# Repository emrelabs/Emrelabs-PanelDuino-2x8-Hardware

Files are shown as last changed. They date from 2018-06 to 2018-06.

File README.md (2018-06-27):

# emrelabs PanelDuino-2x8 Hardware

Please support us:
https://www.tindie.com/products/emrelabs/panelduino-2x8-smart-display/

panelduino-2x8

panelduino-2

panelduino-1

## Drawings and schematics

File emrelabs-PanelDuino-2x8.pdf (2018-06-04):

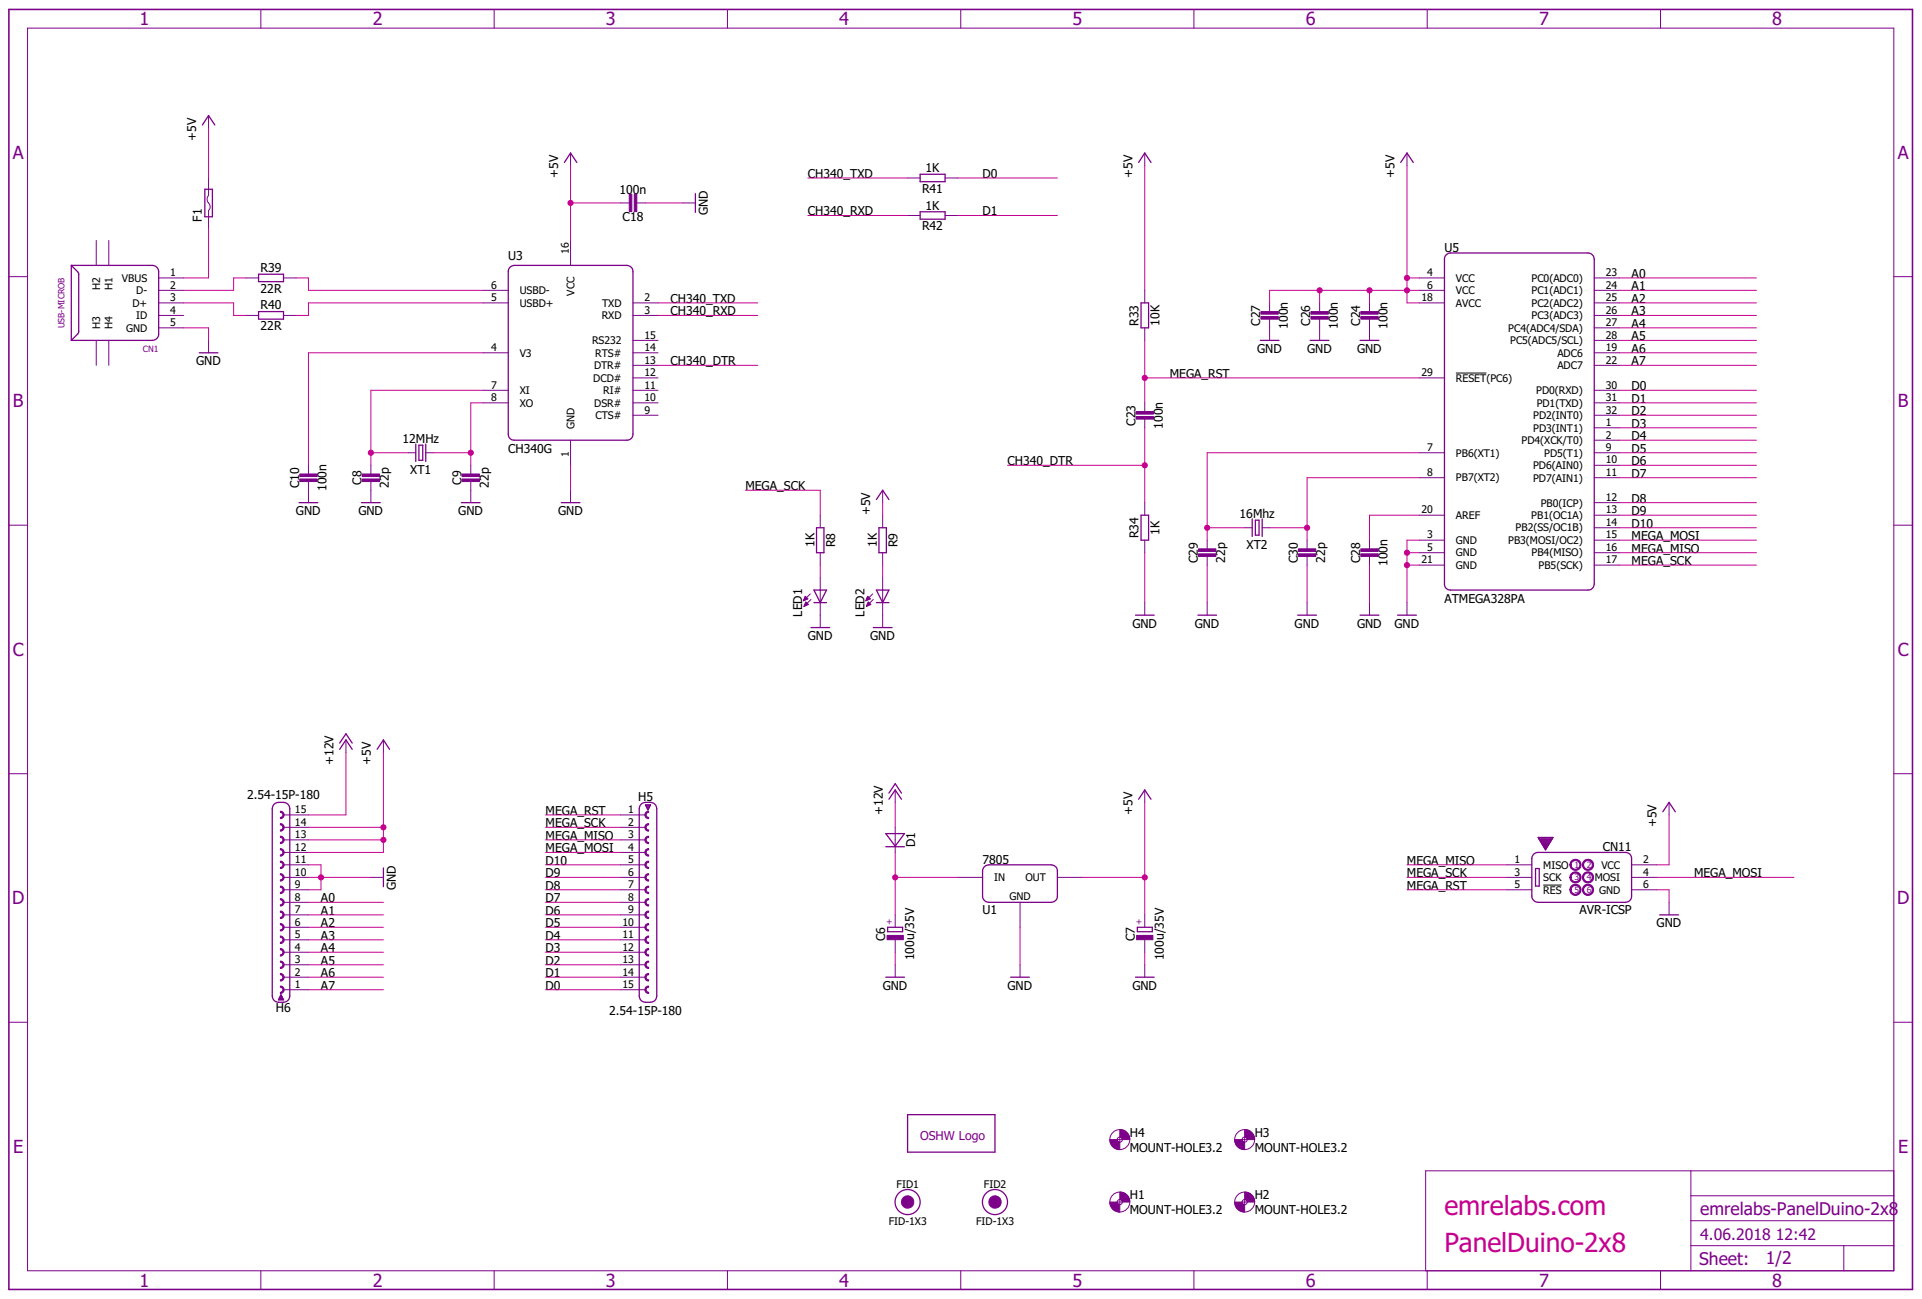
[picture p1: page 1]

RESET(PC6) 29 R33 R34 C23

XI 7 | 14 CTS# 13 DCD# 12 RI#

emrelabs.com PanelDuino-2x8

Sheet: 1/2

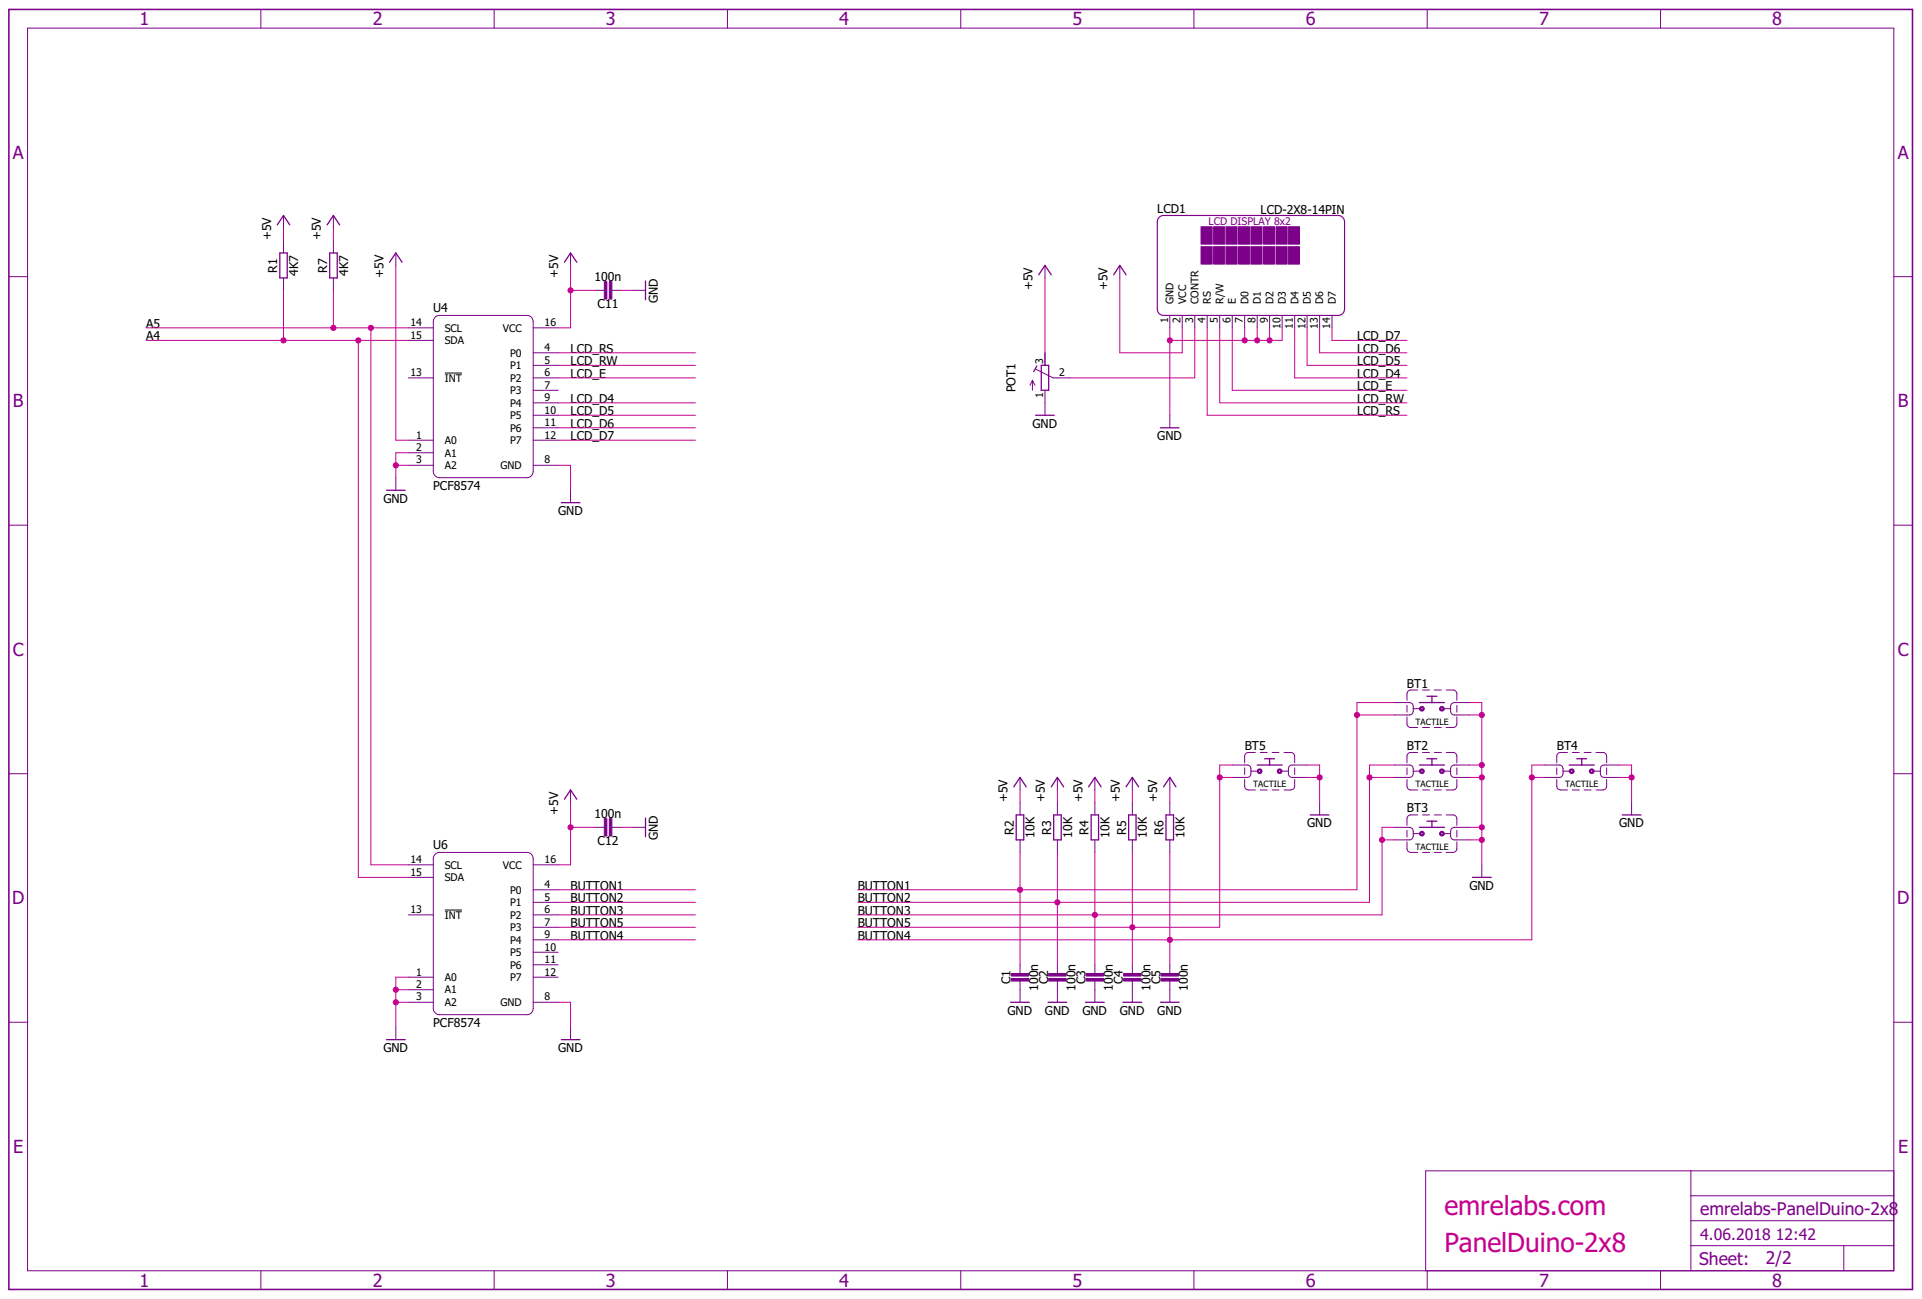
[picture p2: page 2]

GND GND GND GND GND

emrelabs.com PanelDuino-2x8

Sheet: 2/2

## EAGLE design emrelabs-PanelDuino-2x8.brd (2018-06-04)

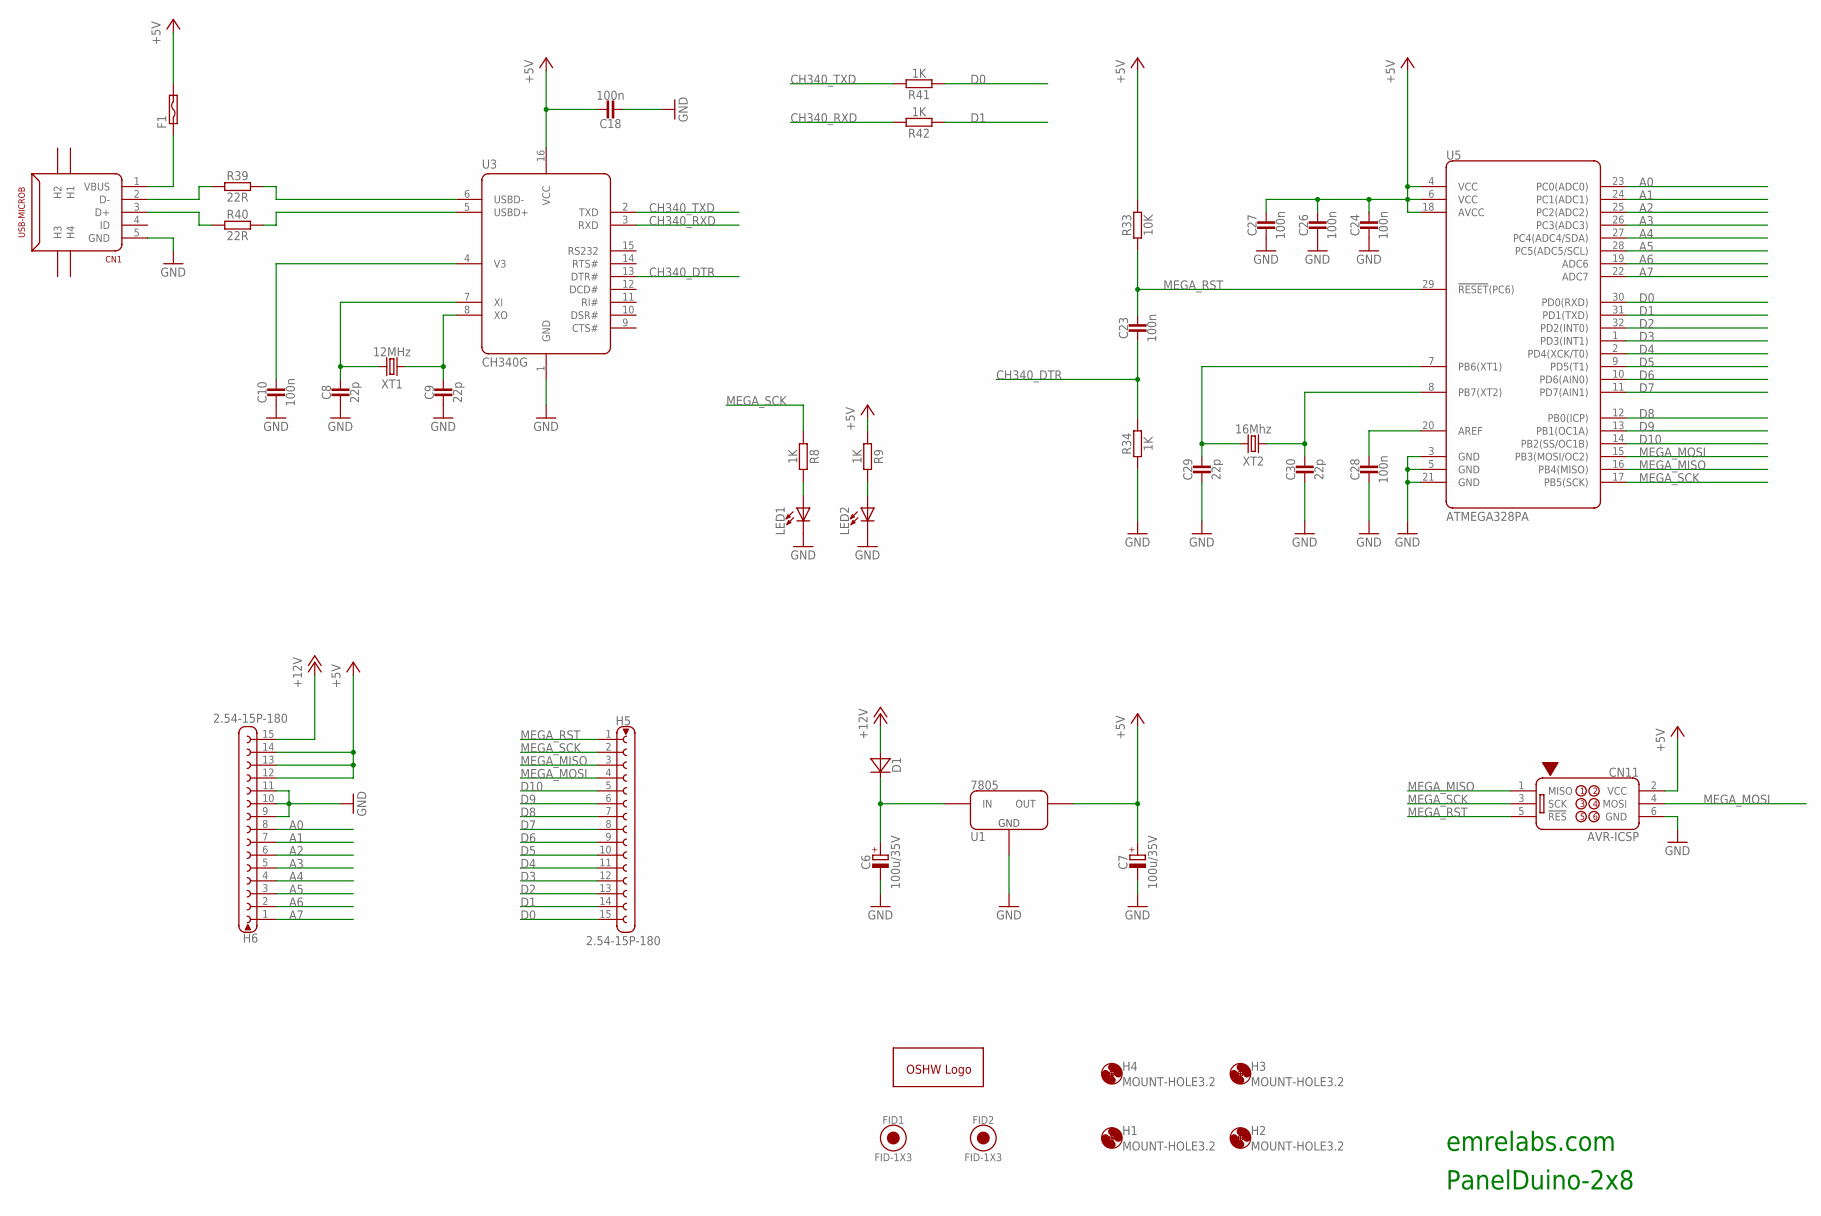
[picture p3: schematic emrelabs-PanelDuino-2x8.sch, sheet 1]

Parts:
C6, C7: 100u/35V; ALU-SIZE-D
C8, C9, C29, C30: 22p; C1206
C10, C18, C23, C24, C26, C27, C28: 100n; C1206
CN1: USB-MICROB; USB-MICRO-B
CN11: AVR-ICSP
D1: D-DO214AC; DO214AC
F1: FUSE-PTC-1206; F1206
FID1, FID2: FID-1X3; FIDUCIAL-1X3MM
H1, H2, H3, H4: MOUNT-HOLE3.2; 3,2
H5, H6: 2.54-15P-180; 2.54-15P
LED1, LED2: LED-1206; LED1206
LOGO1: OSHWLOGOLOGO5MM; OSHW_5MM
R8, R9, R34, R41, R42: 1K; R1206
R33: 10K; R1206
R39, R40: 22R; R1206
U1: 7805; DPAK
U3: CH340G; SOIC-16
U5: ATMEGA328PA; TQFP32-6X6-P0.8
XT1: 12MHz; XT-HC49
XT2: 16Mhz; XT-HC49

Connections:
+5V: C7.+, C18.1, C24.1, C26.1, C27.1, CN11.2 (VCC), F1.2, H6.12, H6.13, H6.14, R9.1, R33.2, U1.3 (OUT), U3.16 (VCC), U5.4 (VCC), U5.6 (VCC), U5.18 (AVCC); also elsewhere on the board
+12V: D1.A, H6.15
A0: H6.8, U5.23 (PC0(ADC0))
A1: H6.7, U5.24 (PC1(ADC1))
A2: H6.6, U5.25 (PC2(ADC2))
A3: H6.5, U5.26 (PC3(ADC3))
A4: H6.4, U5.27 (PC4(ADC4/SDA)); also elsewhere on the board
A5: H6.3, U5.28 (PC5(ADC5/SCL)); also elsewhere on the board
A6: H6.2, U5.19 (ADC6)
A7: H6.1, U5.22 (ADC7)
CH340_DTR: C23.2, R34.2, U3.13 (DTR#)
CH340_RXD: R42.2, U3.3 (RXD)
CH340_TXD: R41.2, U3.2 (TXD)
D0: H5.15, R41.1, U5.30 (PD0(RXD))
D1: H5.14, R42.1, U5.31 (PD1(TXD))
D2: H5.13, U5.32 (PD2(INT0))
D3: H5.12, U5.1 (PD3(INT1))
D4: H5.11, U5.2 (PD4(XCK/T0))
D5: H5.10, U5.9 (PD5(T1))
D6: H5.9, U5.10 (PD6(AIN0))
D7: H5.8, U5.11 (PD7(AIN1))
D8: H5.7, U5.12 (PB0(ICP))
D9: H5.6, U5.13 (PB1(OC1A))
D10: H5.5, U5.14 (PB2(SS/OC1B))
GND: C6.-, C7.-, C8.2, C9.2, C10.2, C18.2, C24.2, C26.2, C27.2, C28.2, C29.2, C30.2, CN1.5 (GND), CN11.6 (GND), H6.9, H6.10, H6.11, LED1.C, LED2.C, R34.1, U1.4 (GND), U3.1 (GND), U5.3 (GND), U5.5 (GND), U5.21 (GND); also elsewhere on the board
MEGA_MISO: CN11.1 (MISO), H5.3, U5.16 (PB4(MISO))
MEGA_MOSI: CN11.4 (MOSI), H5.4, U5.15 (PB3(MOSI/OC2))
MEGA_RST: C23.1, CN11.5 (!RES!), H5.1, R33.1, U5.29 (!RESET!(PC6))
MEGA_SCK: CN11.3 (SCK), H5.2, R8.1, U5.17 (PB5(SCK))
unnamed: C6.+, D1.C, U1.1 (IN)
unnamed: C10.1, U3.4 (V3)
unnamed: LED1.A, R8.2
unnamed: LED2.A, R9.2
unnamed: CN1.1 (VBUS), F1.1
unnamed: C28.1, U5.20 (AREF)
unnamed: C30.1, U5.8 (PB7(XT2)), XT2.1
unnamed: C9.1, U3.8 (XO), XT1.1
unnamed: C8.1, U3.7 (XI), XT1.2
unnamed: C29.1, U5.7 (PB6(XT1)), XT2.2
unnamed: CN1.2 (D-), R39.1
unnamed: CN1.3 (D+), R40.1
unnamed: R39.2, U3.6 (USBD-)
unnamed: R40.2, U3.5 (USBD+)

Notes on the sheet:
PanelDuino-2x8
emrelabs.com

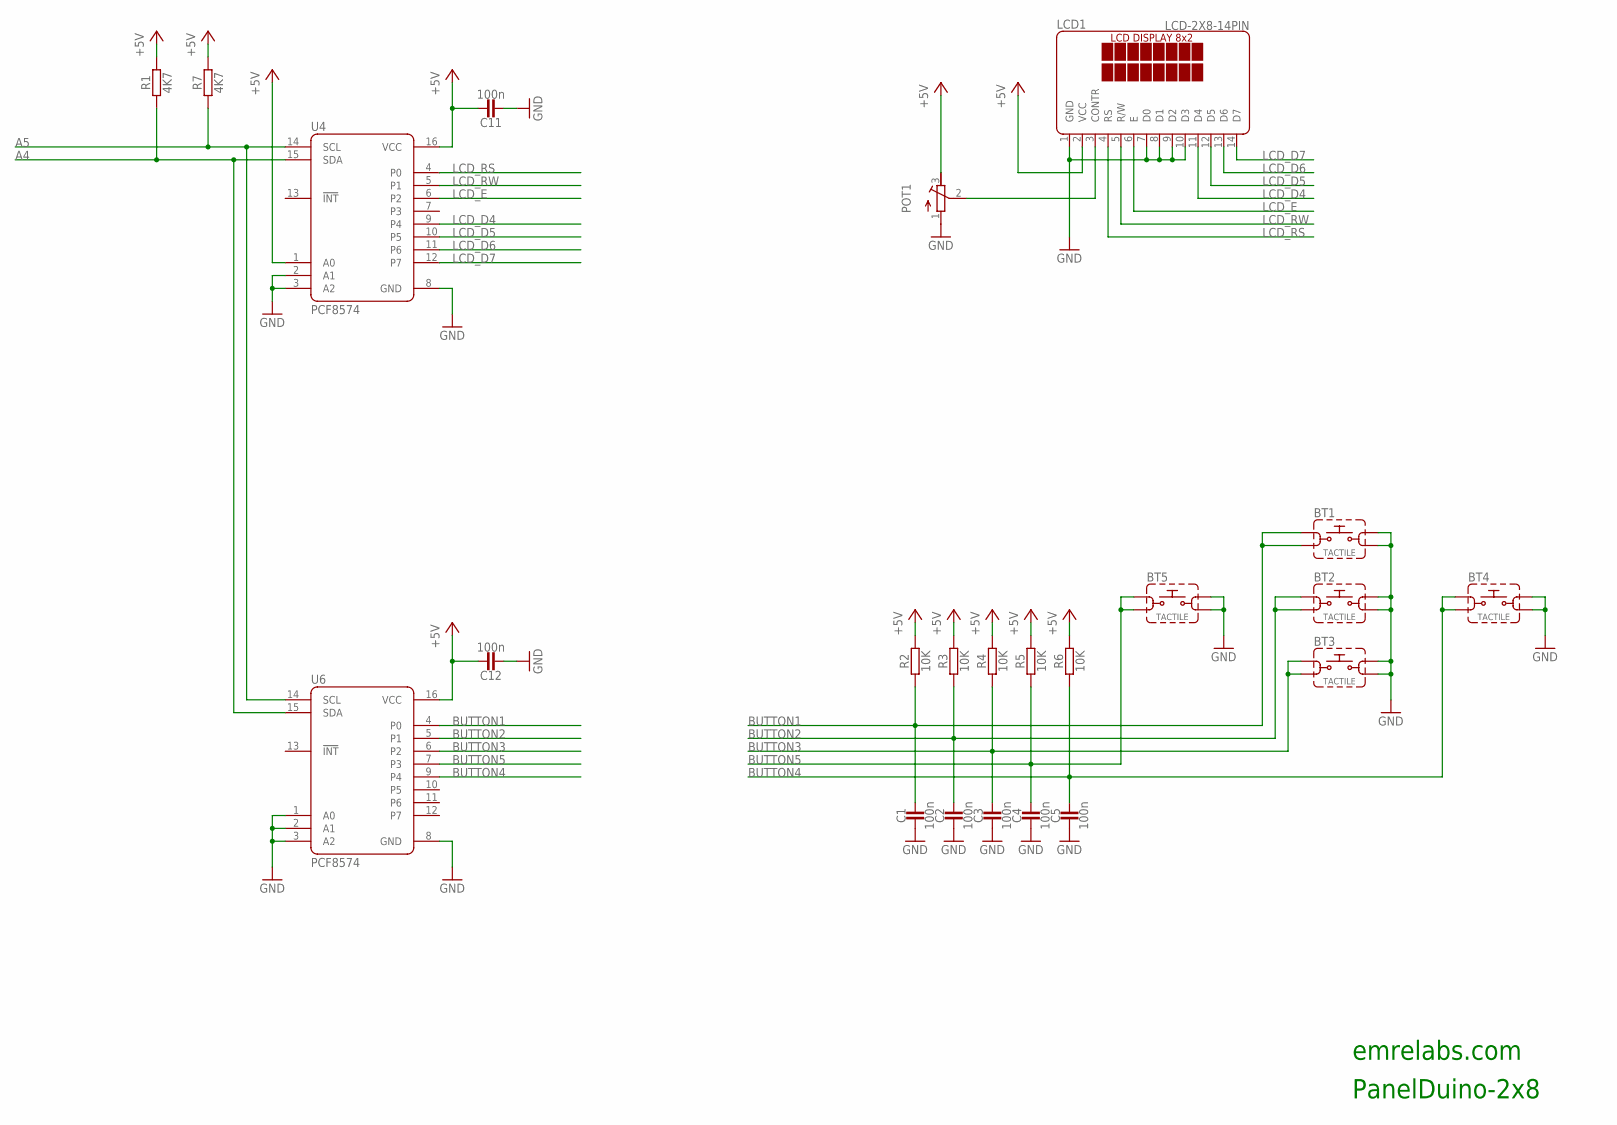
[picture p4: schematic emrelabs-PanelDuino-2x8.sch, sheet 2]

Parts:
BT1, BT2, BT3, BT4, BT5: TACTILE; TACTILE-6X6-DIP
C1, C2, C3, C4, C5, C11, C12: 100n; C1206
LCD1: LCD-2X8-14PIN; 2X8-LCD-14PIN
POT1: R-TRIM-5X4.5MM
R1, R7: 4K7; R1206
R2, R3, R4, R5, R6: 10K; R1206
U4, U6: PCF8574; SOIC-16W

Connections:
+5V: C11.1, C12.1, LCD1.2 (VCC), POT1.3 (E), R1.2, R2.2, R3.2, R4.2, R5.2, R6.2, R7.2, U4.1 (A0), U4.16 (VCC), U6.16 (VCC); also elsewhere on the board
A4: R1.1, U4.15 (SDA), U6.15 (SDA); also elsewhere on the board
A5: R7.1, U4.14 (SCL), U6.14 (SCL); also elsewhere on the board
BUTTON1: BT1.1A, BT1.1B, C1.1, R2.1, U6.4 (P0)
BUTTON2: BT2.1A, BT2.1B, C2.1, R3.1, U6.5 (P1)
BUTTON3: BT3.1A, BT3.1B, C3.1, R4.1, U6.6 (P2)
BUTTON4: BT4.1A, BT4.1B, C5.1, R6.1, U6.9 (P4)
BUTTON5: BT5.1A, BT5.1B, C4.1, R5.1, U6.7 (P3)
GND: BT1.2A, BT1.2B, BT2.2A, BT2.2B, BT3.2A, BT3.2B, BT4.2A, BT4.2B, BT5.2A, BT5.2B, C1.2, C2.2, C3.2, C4.2, C5.2, C11.2, C12.2, LCD1.1 (GND), LCD1.7 (D0), LCD1.8 (D1), LCD1.9 (D2), LCD1.10 (D3), POT1.1 (A), U4.2 (A1), U4.3 (A2), U4.8 (GND), U6.1 (A0), U6.2 (A1), U6.3 (A2), U6.8 (GND); also elsewhere on the board
LCD_D4: LCD1.11 (D4), U4.9 (P4)
LCD_D5: LCD1.12 (D5), U4.10 (P5)
LCD_D6: LCD1.13 (D6), U4.11 (P6)
LCD_D7: LCD1.14 (D7), U4.12 (P7)
LCD_E: LCD1.6 (E), U4.6 (P2)
LCD_RS: LCD1.4 (RS), U4.4 (P0)
LCD_RW: LCD1.5 (R/W), U4.5 (P1)
unnamed: LCD1.3 (CONTR), POT1.2 (S)

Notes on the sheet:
PanelDuino-2x8
emrelabs.com

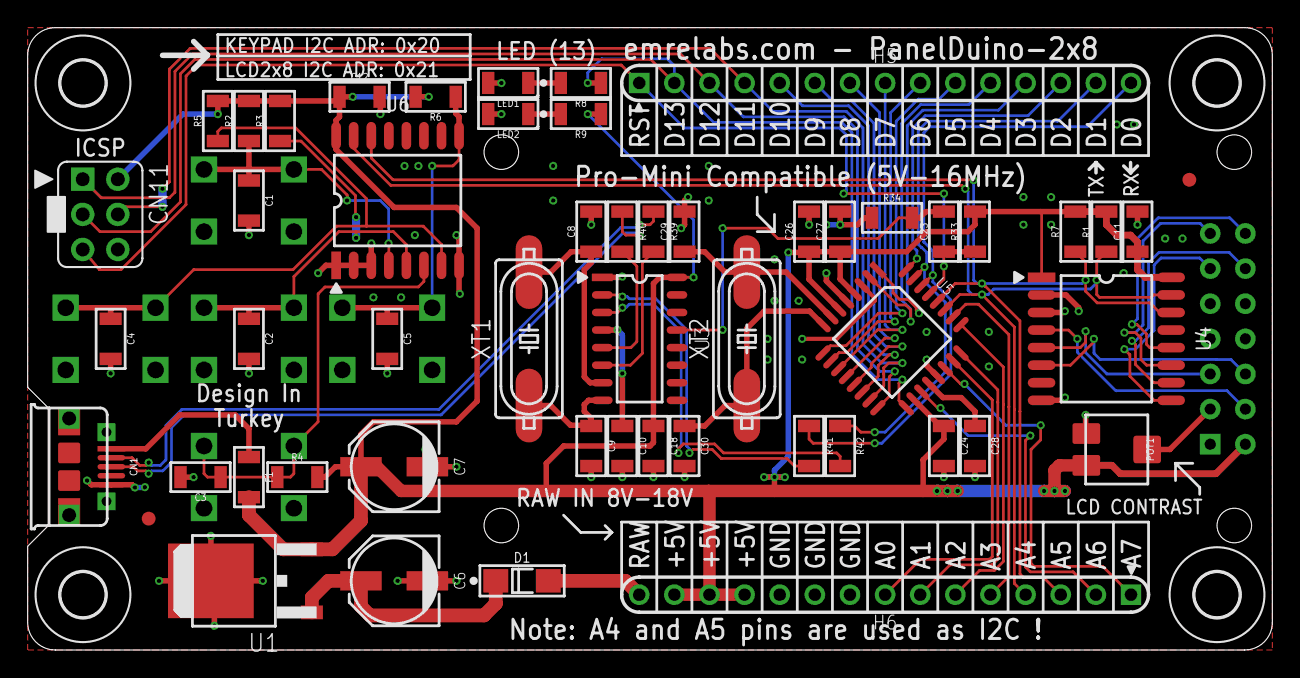
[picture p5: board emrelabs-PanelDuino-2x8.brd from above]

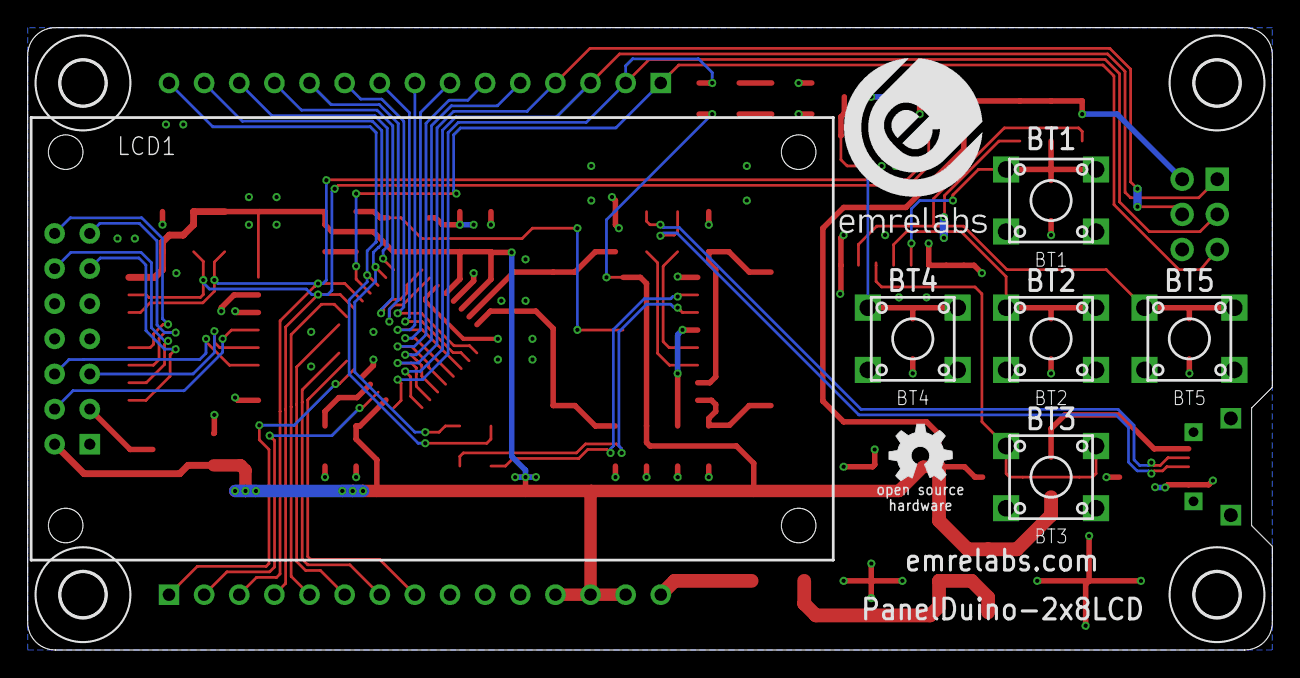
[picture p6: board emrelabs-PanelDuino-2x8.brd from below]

Board: 2 copper layers, 90.0 x 45.0 mm, 64 parts (7 on the bottom side), 56 nets.
